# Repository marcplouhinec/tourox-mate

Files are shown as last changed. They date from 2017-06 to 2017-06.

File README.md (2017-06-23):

# Tourox Mate

## Introduction
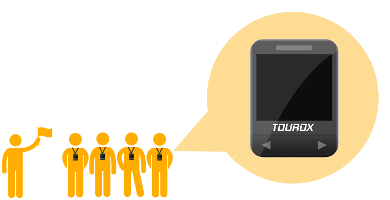
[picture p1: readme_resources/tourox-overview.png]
Product overview


Tourox Mate is a device that helps tour guides during group travels. It is worn by each participant with a lanyard.
Each device contains a chip that connects it to internet via the cellular network. The tour guide is thus in permanent
contact with each member of his group via his smartphone.

Tourox Mate provides the following features:
* During travels with a great number of people, the tour guide is immediately warned if a member of the group doesn't
  follow anymore or leave unexpectedly.
  
  Use case: person not following
* During outdoor visits, it happens that the tour guide allows his group members to explore a place by themselves
  (market, city-center, ...) during a given period of time before gathering again in order to resume the visit.
  Thanks to its internet connection, Tourox Mate can:
  * Allow the tour guide to visualize in real-time the geographical position of each group member on a map.
  
    Use case: get tourist location
  * Let a group member to call the guide in case of a problem.
  
    Use case: tourist calls guide
  * Let the guide to call his group members in case they are late or too far.
  
    Use case: guide calls tourist
* Finally, Tourox Mate can also replace voice transmission devices.

  Use case: voice transmitter

Technically, Tourox Mate is made of the following parts:
 * A physical device, made with electronics, a 3D printed case and a firmware.
 * A web-server collecting information from devices over internet.
 * An Android application for the Tour Guide that allows him to configure and interact with the physical devices.
 
## Build
Please follow the following instructions if you want to build Tourox Mate yourself:
1. [Build the physical device.](device/README.md)
2. [Build and setup the web-server](webserver/README.md)
2. [Build and setup the tour guide Android application](android/README.md)

## Usage
The current version is a prototype so only the basic features are available.

To start using Tourox Mate, turn on the device with the slide switch and open the "Tourox Device Tester" app on the
Android device. The Android application scans for bluetooth devices and quickly find the Tourox Mate:

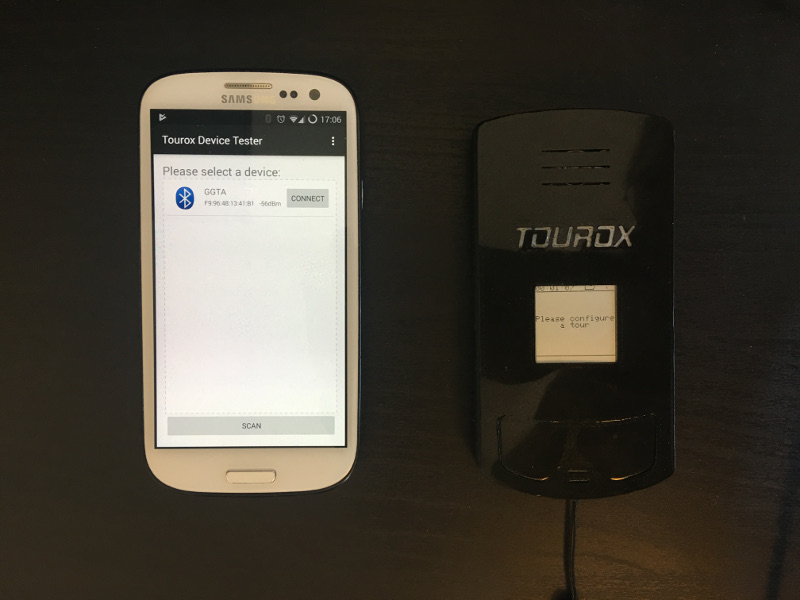
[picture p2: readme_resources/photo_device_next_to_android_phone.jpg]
Device next to Android phone


When you select this device, the following screen opens:

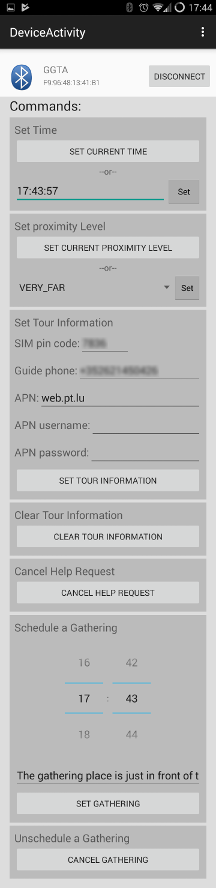
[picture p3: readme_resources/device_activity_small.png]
Device activity


It allows you to execute the following actions:
* Set the device time.
* Set the proximity level that reflects the distance between the tour guide and a tourist wearing the device.
* Configure a tour with the following properties:
  * The SIM card PIN number.
  * The [APN](https://en.wikipedia.org/wiki/Access_Point_Name) with the corresponding username and password.
    These values can be found on the telecom provider contract or support website.
  * The tour guide phone number. It is the number the device will call when the tourist presses the "HELP" button.
* Clear the tour configuration.
* Cancel a help request on the device.
* Schedule a gathering with the following properties:
  * The gathering time.
  * A gathering text description.
* Un-schedule a gathering.

To start using the device, set the time and proximity level, and configure a tour:

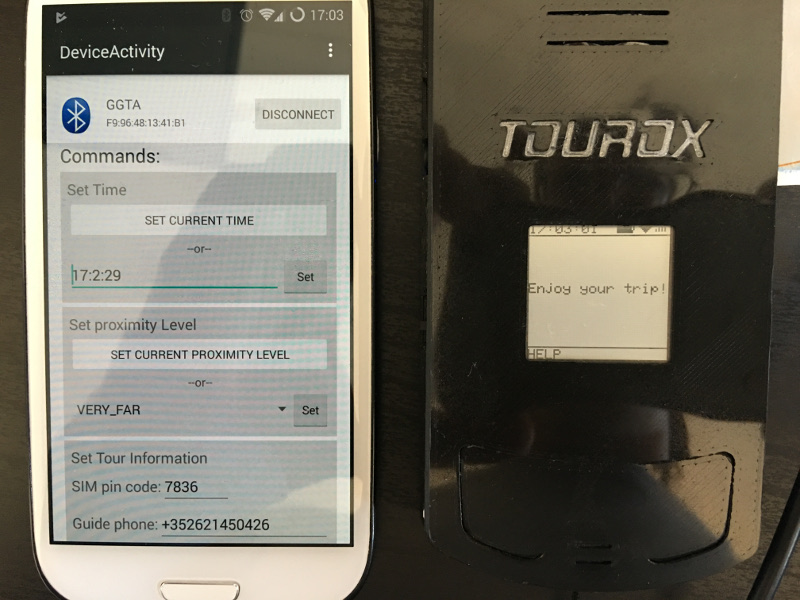
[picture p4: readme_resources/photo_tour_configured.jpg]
Tour configured


From the device, a tourist can call the tour guide by pressing on the help button:

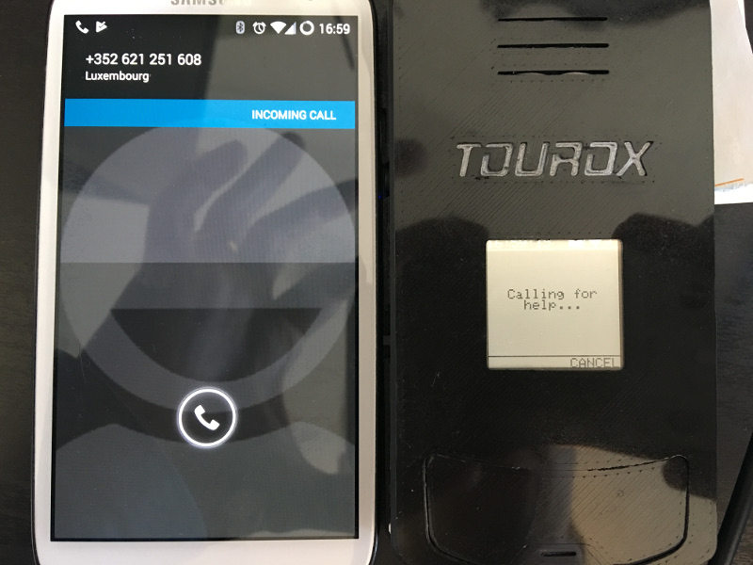
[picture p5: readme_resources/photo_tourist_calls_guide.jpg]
Tourist calls guide


In a similar way, the tour guide can also call the device by dialing its number:

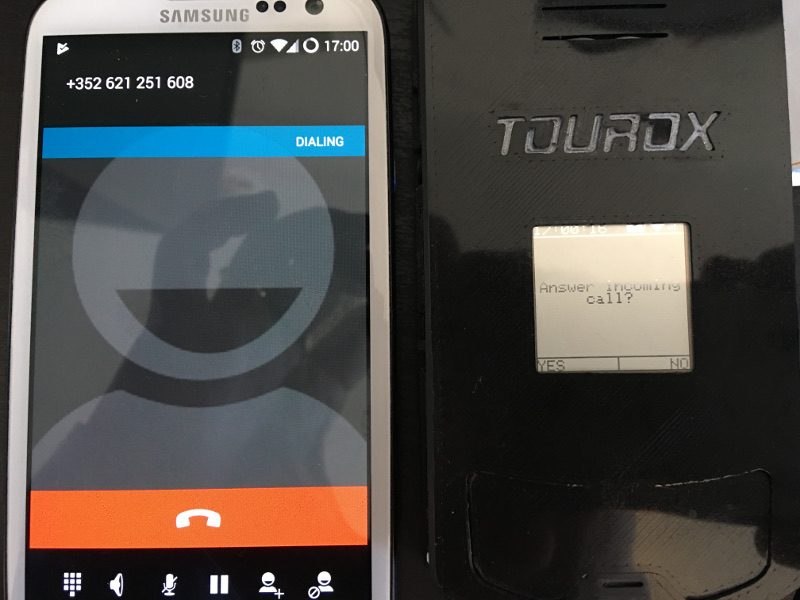
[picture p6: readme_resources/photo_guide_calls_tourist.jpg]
Guide calls tourist


The tour guide can see the device location by browsing to the webserver URL:

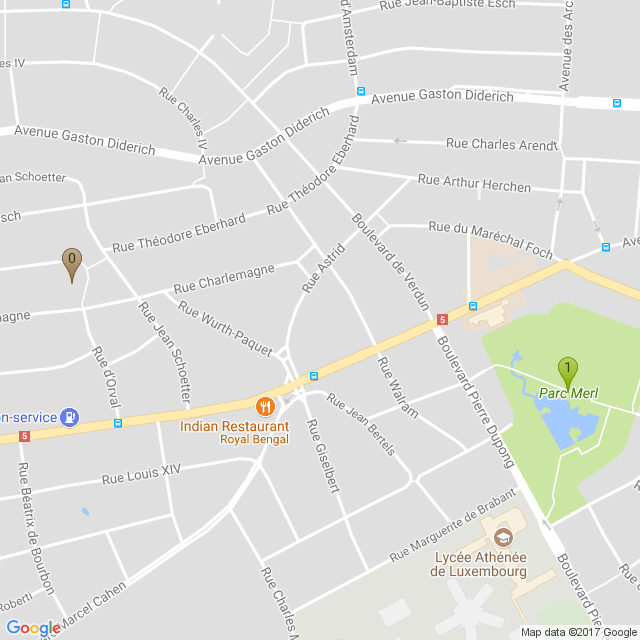
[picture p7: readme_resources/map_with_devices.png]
Map with devices


When the tour guide schedules a gathering, the device shows the gathering description:

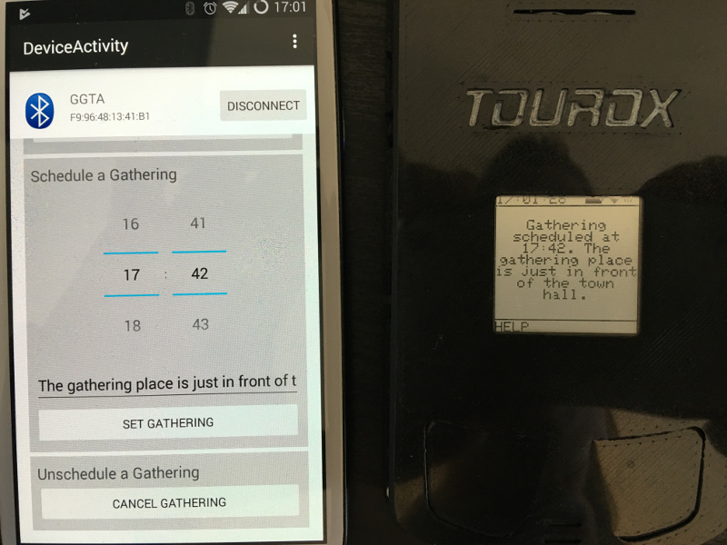
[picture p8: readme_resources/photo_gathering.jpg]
Gathering


Canceling a gathering reverts the device to its normal state.

Finally, to disconnect the device from internet, the tour guide can clear the tour configuration.

___

Thank you for reading! don't hesitate to contact me if you have any remark or question!

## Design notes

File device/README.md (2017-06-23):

# Tourox Mate - Device

## Introduction
As explained in the [parent document](../README.md), the goal of this device is to allow a tour guide to stay
in permanent contact with his group members during a trip. Each tourist wears a device with a lanyard.

The current version has the following communication capabilities:
* It can connect directly to the tour guide's smartphone via [BLE](https://en.wikipedia.org/wiki/Bluetooth_Low_Energy).
  This protocol allows the guide to configure a device, send text messages and measure the distance.
* It can use the standard GSM network to give phone calls (tour guide to tourist and vice versa).
* It can get its geographical position (latitude and longitude) thanks to the cellular network.
* It can connect to a server over internet via [GPRS](https://en.wikipedia.org/wiki/General_Packet_Radio_Service) in
  order to regularly send its location.

## Components
The following diagram shows the components and how they are connected:

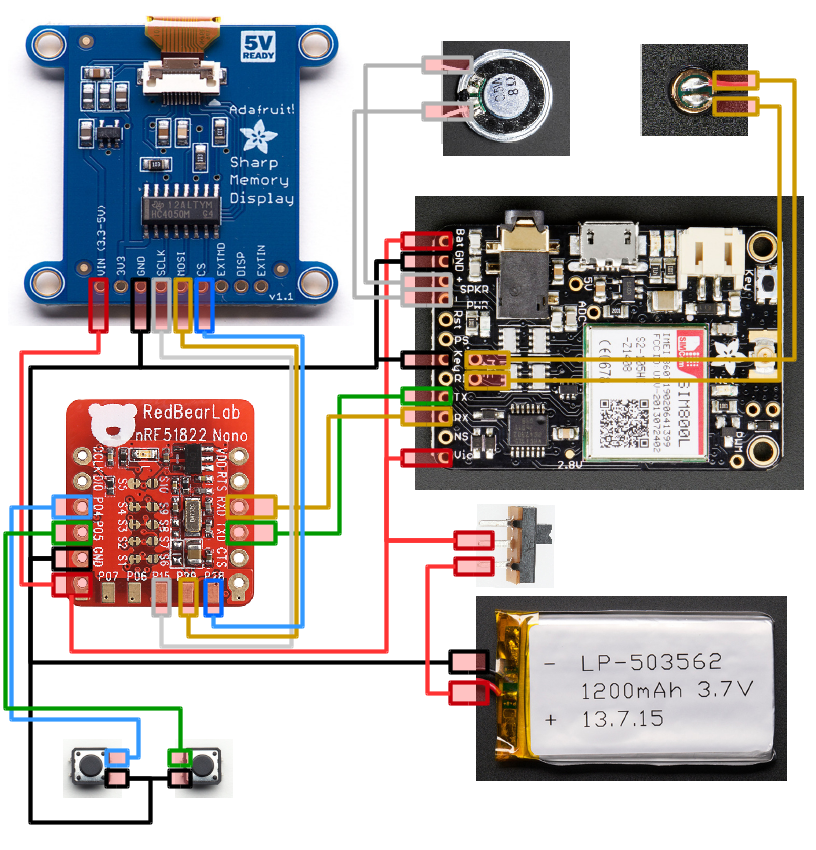
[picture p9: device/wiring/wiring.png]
Components and wires


The brain of the system is a [nRF51822](https://www.nordicsemi.com/eng/Products/Bluetooth-low-energy/nRF51822), a
low-power SoC containing an ARM Cortex M0 CPU and a BLE module. It is located on the 
[RedBearLab BLE Nano](http://redbearlab.com/blenano/) board. For development I also used a
[nRF51 DK](https://www.nordicsemi.com/eng/Products/nRF51-DK) board, which is optional but more convenient at this stage.

The screen is a low-power [SHARP LCD display](https://www.adafruit.com/product/1393) packaged on a board produced
by AdaFruit.

The GSM module is an [AdaFruit FONA](https://www.adafruit.com/product/1946) powered with a
[SIM800](http://simcomm2m.com/En/module/detail.aspx?id=138) chip. It handles voice calls and provides an
internet connection. A typical [SIM card](https://en.wikipedia.org/wiki/Subscriber_identity_module)
(there is a socket under the board) and a [uFL GSM Antenna](https://www.adafruit.com/product/1991) are necessary.
In addition, this module can even recharge a LiPo battery.

Finally, the device also contains a [1200mAh LiPo battery](https://www.adafruit.com/product/258),
a [8 ohm 0.5W speaker](https://www.adafruit.com/product/1890),
an [electret microphone](https://www.adafruit.com/product/1064),
two [tactile buttons](https://www.adafruit.com/product/367),
a [SPDT Slide Switch](https://www.adafruit.com/product/805),
[stranded-core 22AWG wires](https://www.adafruit.com/product/3111),
[0.1" male](https://www.adafruit.com/product/392) and [female headers](https://www.adafruit.com/product/598).

## Building steps

### Case 3D printing
The case as been designed with [OpenSCAD](http://www.openscad.org/), a tool that allows developers to create
3D models with a scripting language. It is free and available on most operating systems. The advantages of using a
scripting language instead of a graphical mouse-controlled CAD software like [Thingiverse](https://www.thingiverse.com/)
is that it is very easy to parametrize (for example sizes and positions can be saved in variables and used by
several parts of the code, which is useful for connectors or components that need to fit together),
it is [VCS-friendly](https://en.wikipedia.org/wiki/Version_control) (for example
difference between several versions of a script can be easily visualized on GitHub) and reusable
[part libraries](https://github.com/openscad/openscad/wiki/Libraries) can be shared on internet. The main disadvantage
is that is it harder to use, especially for beginners.

In order to visualize the 3D model, setup OpenSCAD on your computer and open the `3dmodel/Box.scad` file. You should
then see something like this:

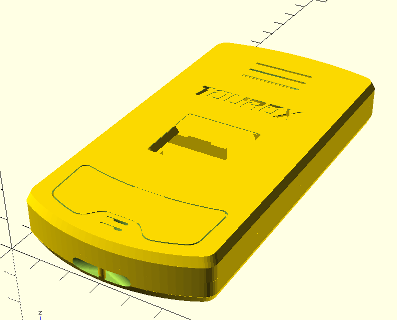
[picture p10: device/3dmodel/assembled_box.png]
3D model - assembled box


Before printing the case, you need to generate [STL files](https://en.wikipedia.org/wiki/STL_(file_format)). To do that,
scroll the text editor to the bottom of the file `3dmodel/Box.scad`:

    //rotate([0, 180, 0])
    Box_assembled(includeBackCover = true, includeFrontCover = true, includeComponents = false);

These two lines generate the assembled box, which cannot be used directly. Modify these two lines like this:

    //rotate([0, 180, 0])
    Box_assembled(includeBackCover = true, includeFrontCover = false, includeComponents = false);

You should then see the following 3D model, which is the back cover:

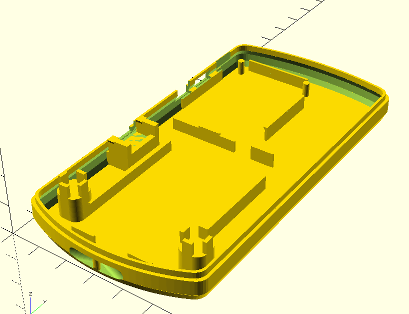
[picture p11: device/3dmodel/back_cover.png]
3D model - back cover


Then render it and export it as `back_cover.stl`.

In order to generate the front cover, modify the last two lines like this:

    rotate([0, 180, 0])
    Box_assembled(includeBackCover = false, includeFrontCover = true, includeComponents = false);

You should then see the following 3D model:

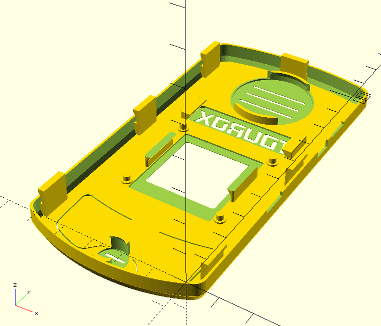
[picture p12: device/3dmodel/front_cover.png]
3D model - front cover


Then render it and export it as `front_cover.stl`.

Finally, if you want, generate the brand label by opening the file `3dmodel/BrandName.scad`, and modify the last
lines like this:

    /*
    difference() {
        BrandName_frame(1, true);
        BrandName_frame(1, false);
    }*/
    
    rotate([0, 180, 0])
        difference() {
            BrandName_coloredBrandName(1, true);
            BrandName_coloredBrandName(1, false);
        }

You should then see something like this:

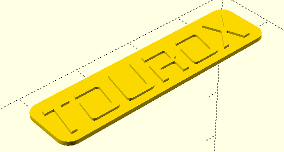
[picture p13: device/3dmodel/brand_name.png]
3D model - brand name


Then render it and export it as `brand_name.stl`.

You can then use your favorite tools to generate [G-code](https://en.wikipedia.org/wiki/G-code) for each STL file and
send them to your 3D printer, with tools like [Slic3r](http://slic3r.org/) +
[Printrun](http://www.pronterface.com/) or [Cura](https://ultimaker.com/en/products/cura-software).

If you are lucky, the result should look like this:

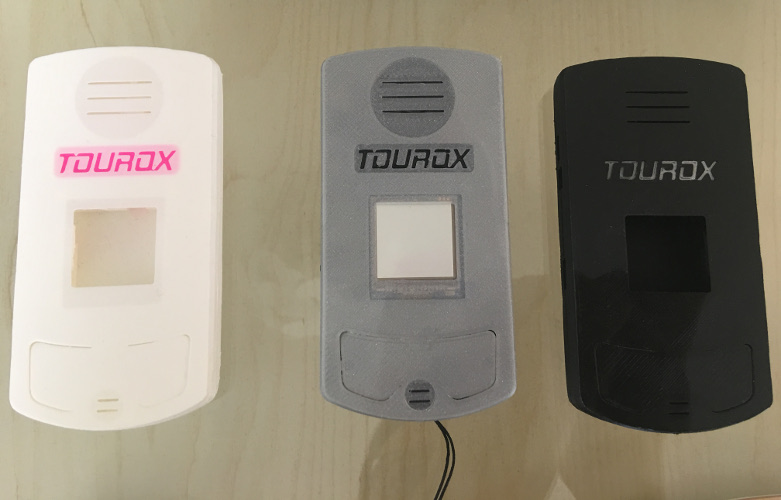
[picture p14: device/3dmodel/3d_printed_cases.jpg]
3D printed cases


### Wiring
Now that the case is ready, it is time to add electronic components in it!

Because 22AWG wire are quite thick, it is important to place components in order to avoid too many wire crossings.
The following schema is useful for preparing wires before soldering them on the back cover:

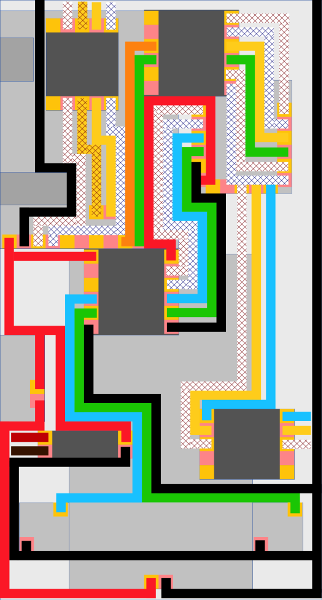
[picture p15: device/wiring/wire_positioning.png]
Wire positioning


To print this schema with the right size, install [LibreOffice](https://www.libreoffice.org/), open and print the file
`wiring/wire_positioning.odg`.
The following photo shows how to prepare the wires according to this schema (the same photo at bigger resolution
is [available here](wiring/photo_wire_positioning.jpg)):

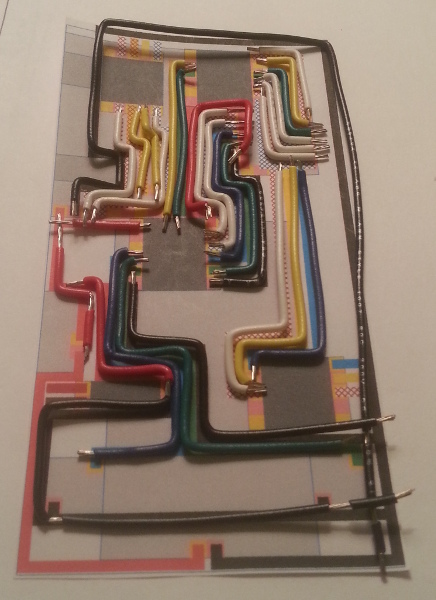
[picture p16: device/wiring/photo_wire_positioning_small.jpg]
Wire positioning photo


As you can see on the schema, 0.1" headers must be prepared at the following size:
* 6 pins for connecting the RedBearLab Nano with the Adafruit FONA.
* 4 pins for connecting the Adafruit FONA with the speaker and microphone (the schema shows 5 pins but you can put less).
* 6 pins for connecting the RedBearLab Nano with the tactile buttons and battery.
* 3 pins for connecting the RedBearLab Nano with the screen (the schema shows 5 pins but you can put less).
* 2 pins for connecting the screen with the battery.

As you can see, the RedBearLab Nano have more soldered wires connected to headers than necessary, but it is useful
for flashing the microcontroller by connecting it to the [MK20 USB Board](http://redbearlab.com/blenano/#mk20usbboard).

The following photo shows the wires soldered and connected to each others (a bigger resolution is
[available here](wiring/photo_wired_components.jpg)):

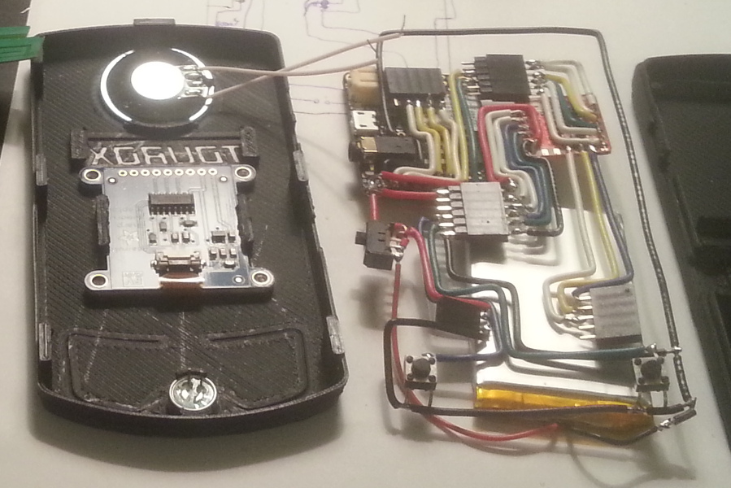
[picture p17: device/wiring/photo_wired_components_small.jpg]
Connected wires photo


Positioning wires on the front cover is much simpler, no need to prepare a shema for that, the following photo
is clear enough:

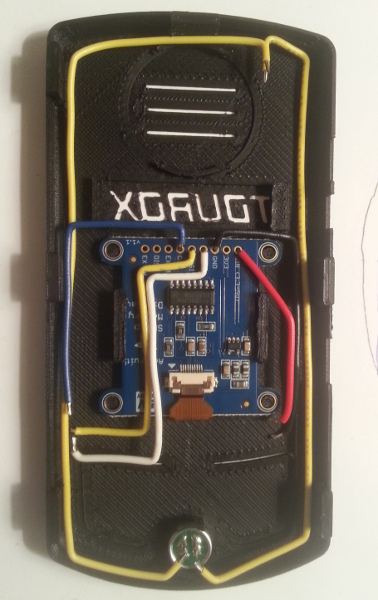
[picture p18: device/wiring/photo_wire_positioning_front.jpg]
Front wires photo


The following photos shows both covers with connected components (a bigger resolution is
[available here](wiring/photo_components_placed_and_connected.jpg)):

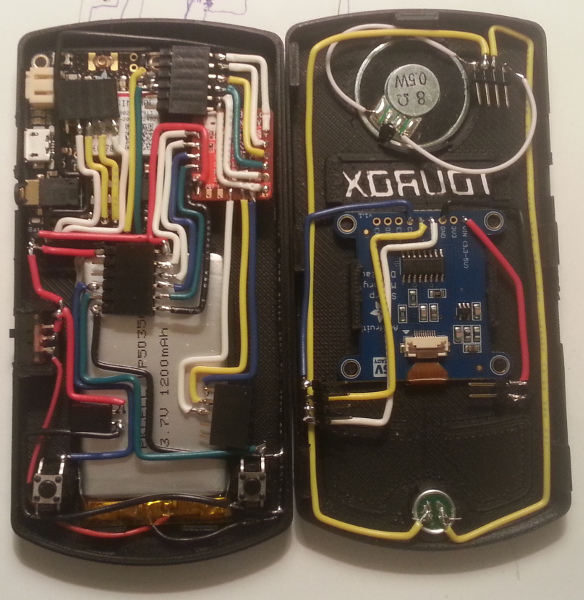
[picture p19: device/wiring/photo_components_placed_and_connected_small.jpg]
Connected components photo


### Electromagnetic shielding
There is a missing but important component is the previous photo: the GSM antenna. If you "naively" put it inside the
case you will experience unexpected resets because the GSM signal interferes with the microcontroller.

To solve this problem, you can create a layer of [aluminium foil](https://en.wikipedia.org/wiki/Aluminium_foil)
in sandwich between two layers of paper. And then put this in the middle of the case with the RedBearLab Nano on one
side (back cover side) and the GSM antenna on the other side (front cover side).

The following photos show how you can reproduce this protection:

* Electromagnetic shield width ([bigger resolution](electromagnetic_shield/photo_shield_width.jpg)):

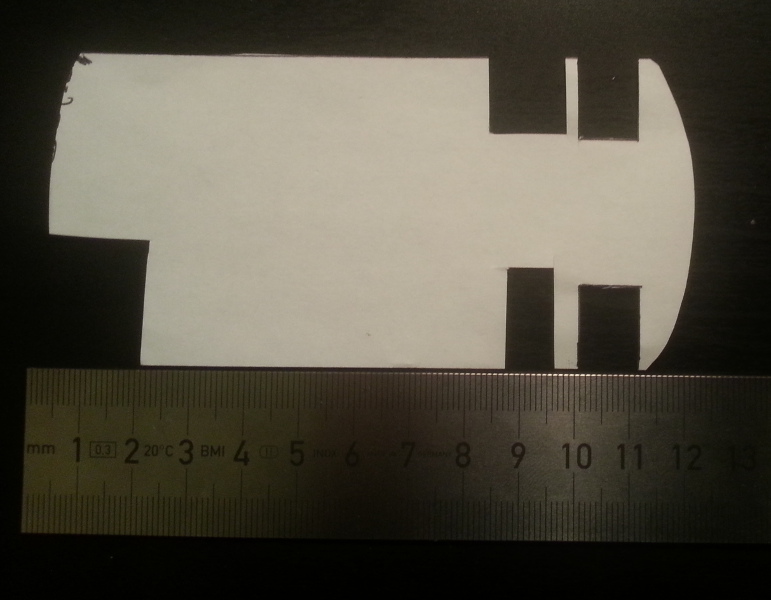
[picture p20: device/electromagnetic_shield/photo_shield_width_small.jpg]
Shield width


* Electromagnetic shield height ([bigger resolution](electromagnetic_shield/photo_shield_height.jpg)):

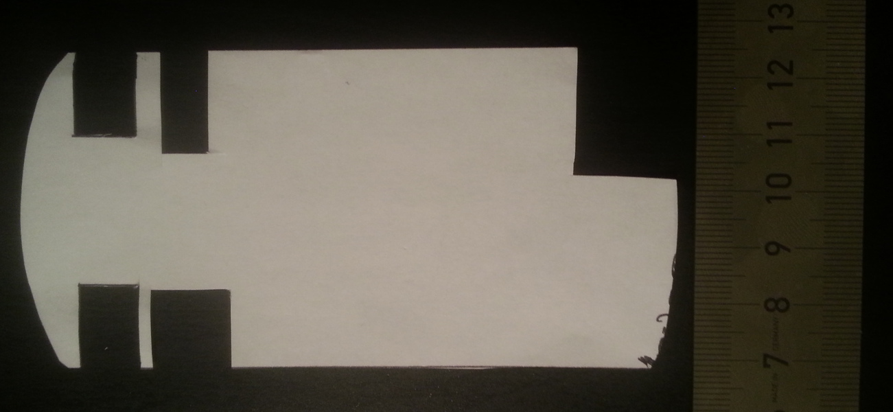
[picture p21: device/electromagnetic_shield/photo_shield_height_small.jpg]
Shield height


* Electromagnetic shield in place ([bigger resolution](electromagnetic_shield/photo_shield_in_place.jpg)):

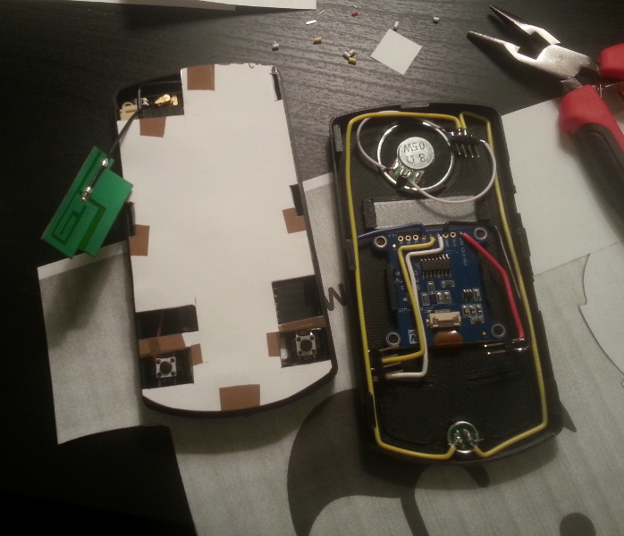
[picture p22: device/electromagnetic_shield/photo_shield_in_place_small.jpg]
in place Shield in place


### Compile and flash the firmware
This is the step where you will discover all your wiring or soldering mistakes! :-)

#### Setup development environment
The following section describes briefly how to setup your environment in order to compile the firmware with
[GCC](https://gcc.gnu.org/).

Detailed information about how to setup [Eclipse IDE](https://www.eclipse.org) can be found in
[this tutorial](https://devzone.nordicsemi.com/tutorials/7/development-with-gcc-and-eclipse/) from Nordic Semiconductor.

1. Setup the [GNU toolchain for ARM Cortex-M](https://developer.arm.com/open-source/gnu-toolchain/gnu-rm/downloads).
2. Add the toolchain into the PATH environment variable. To check if it is correctly set, open a new terminal
   and type the following command:
   ```bash
   arm-none-eabi-gcc --version
   ```
   The result should be something like this:
   ```text
   arm-none-eabi-gcc (GNU Tools for ARM Embedded Processors 6-2017-q1-update) 6.3.1 20170215 (release) [ARM/embedded-6-branch revision 245512]
   Copyright (C) 2016 Free Software Foundation, Inc.
   This is free software; see the source for copying conditions.  There is NO
   warranty; not even for MERCHANTABILITY or FITNESS FOR A PARTICULAR PURPOSE.
   ```
3. Setup GNU Make:
  * On Linux, setup the package provided by your distribution, like `build-essential` on Debian.
  * On Windows, setup the GNU ARM Eclipse Windows Build Tools package from the
    [GNU ARM Eclipse plug-in project](http://gnuarmeclipse.github.io/windows-build-tools/).
  * On MAC OSX, setup the 
    [Xcode tools](https://developer.apple.com/library/mac/documentation/Darwin/Reference/ManPages/man1/gnumake.1.html).
  * Check the result by opening a new terminal and by typing the following command:
     ```bash
     make -v
     ```
     The result should be something like this:
     ```text
     GNU Make 3.81
     Copyright (C) 2006  Free Software Foundation, Inc.
     This is free software; see the source for copying conditions.
     There is NO warranty; not even for MERCHANTABILITY or FITNESS FOR A
     PARTICULAR PURPOSE.
     
     This program built for i386-apple-darwin11.3.0
     ```
4. Setup the nRF5x-Command-Line-Tools
  * Download the nRF5x-Command-Line-Tools from the 
    [Nordic Semiconductor download page](https://www.nordicsemi.com/eng/Products/Bluetooth-low-energy/nRF51822).
  * On Linux and MAC OSX, unzip the tools archive and add `<nRF5x-Command-Line-Tools>/mergehex` into the PATH
    environment variable.
  * Check the result by opening a new terminal and by typing the following command:
     ```bash
     mergehex --version
     ```
     The result should be something like this:
     ```text
     mergehex version: 9.5.0
     ```
5. Download and unzip the [Nordic nRF5x SDK 8.1.0](http://developer.nordicsemi.com/) (a greater version may not be
   compatible).
6. Edit the SDK Makefile with a text editor:
  * On Linux and MAC OSX, open `<SDK>/components/toolchain/gcc/Makefile.posix`.
  * On Windows, open `<SDK>/components/toolchain/gcc/Makefile.posix`.
  * Replace the `GNU_INSTALL_ROOT` property value by the path where you setup the GNU toolchain and `GNU_VERSION`
    by the toolchain version:
    ```text
    GNU_INSTALL_ROOT := /opt/gcc-arm-none-eabi-6-2017-q1-update
    GNU_VERSION := 6.3.1
    GNU_PREFIX := arm-none-eabi
    ```
7. With a text editor open the project file `device/firmware/Makefile` and replace the following property values:
  * `TARGET_BOARD` with `TARGET_BOARD_IS_BLE_NANO`
  * `SDK_PATH` with the path where you unzipped the Nordic nRF5x SDK (e.g. `/opt/nRF51_SDK_8.1.0_b6ed55f`).

#### Configure the firmware
The firmware needs the URL of the [webserver](../webserver) where it will send the device location. It means that
you need to have a server with a public IP address that the device can reach from the GPRS connection.

If you want you can pause here and start installing the [webserver](../webserver). Once you have the URL of your
server, you can resume this firmware configuration. A typical URL would be "http://myhostname.com/tourox/".

To configure the firmware, open the file `service/service_geolocation.c` and find the following constants:
```c
#define SEND_GEOLOCATION_URL               "http://www.tourox.io/sl/imeiimeiimeiime/-xx.dddddd/-xx.dddddd"
#define SEND_GEOLOCATION_URL_LENGTH        (sizeof(SEND_GEOLOCATION_URL))
#define SEND_GEOLOCATION_URL_IMEI_POS      (sizeof("http://nwww.tourox.io/sl"))
#define SEND_GEOLOCATION_URL_LNGLAT_POS    (sizeof("http://www.tourox.io/sl/imeiimeiimeiime"))
```
replace them by
```c
#define SEND_GEOLOCATION_URL               "http://myhostname.com/tourox/sl/imeiimeiimeiime/-xx.dddddd/-xx.dddddd"
#define SEND_GEOLOCATION_URL_LENGTH        (sizeof(SEND_GEOLOCATION_URL))
#define SEND_GEOLOCATION_URL_IMEI_POS      (sizeof("http://myhostname.com/tourox/sl"))
#define SEND_GEOLOCATION_URL_LNGLAT_POS    (sizeof("http://myhostname.com/tourox/sl/imeiimeiimeiime"))
```

> Note the pattern: replace "http://www.tourox.io/" with your URL "http://myhostname.com/tourox/".

In fact it is a bad practice to hardcode an URL inside a firmware. Instead, a better solution would be to set
it each time the Android application configures the device. But it is good enough for a prototype. :-)

#### Compile the firmware
To compile with a command line, type the following commands:
```bash
make
make nrf51422_xxac_s110 package
```

#### Prepare the MK20 USB board
The [MK20 USB board](http://redbearlab.com/blenano/#mk20usbboard) is necessary for flashing the Nano board:

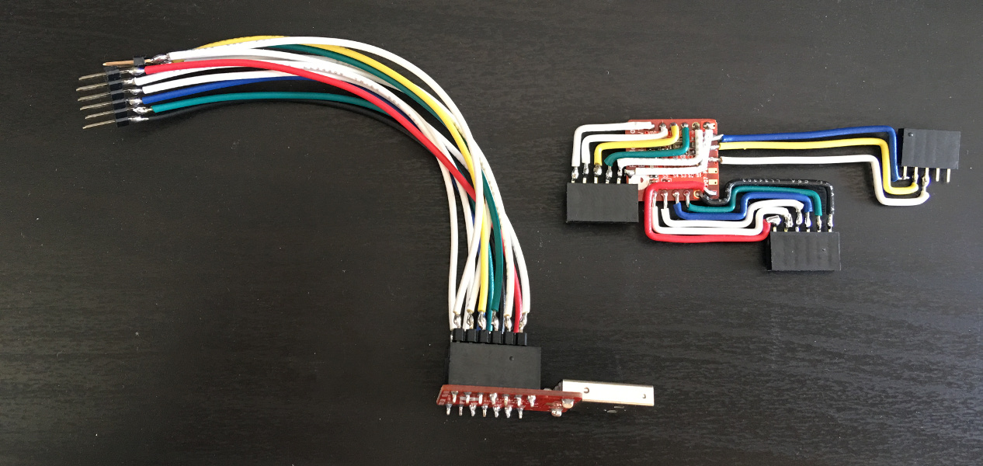
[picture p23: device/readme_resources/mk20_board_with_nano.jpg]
MK20 board with Nano


Solder wires and headers on the MK20 USB board. The wire color code must be the same as the Nano board:

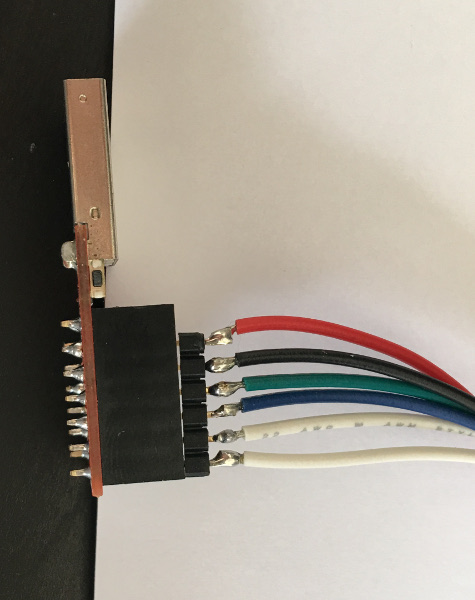
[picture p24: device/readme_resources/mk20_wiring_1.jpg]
MK20 wiring 1

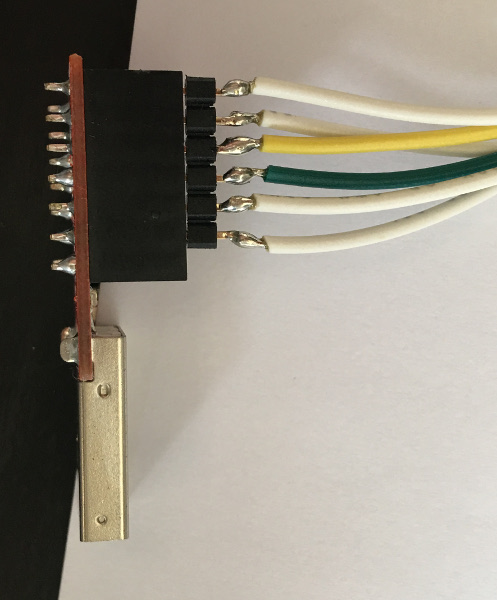
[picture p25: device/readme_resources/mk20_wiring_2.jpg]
MK20 wiring 2


A detailed tutorial about how to compile and flash the board is [available here](http://redbearlab.com/nrf51822-sdk).

#### Flash the RedBearLab Nano board
Plug the RedBearLab Nano board to the MK20 USB board and the later to the computer:

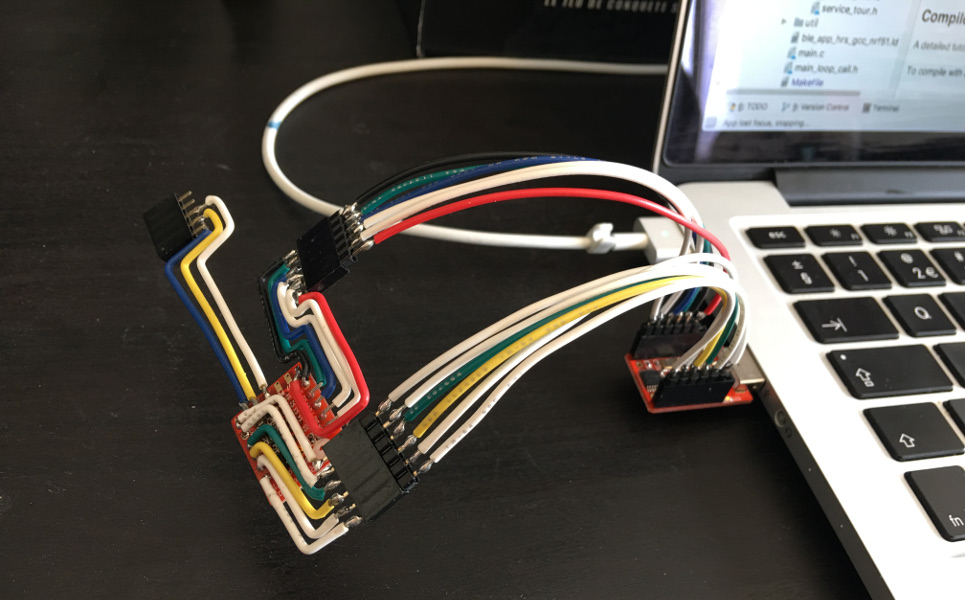
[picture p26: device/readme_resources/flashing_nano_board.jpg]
Flash Nano board


A new USB drive will appear with the "MBED" name.
Copy the file `_build/nrf51422_xxac_s110_packed.hex` into this drive.

After few seconds the MBED drive will refresh itself without the .hex file you just copied. At this stage, unplug the
board and put back the Nano into the Tourox case and close it.

If everything works as expected, you should see it working!

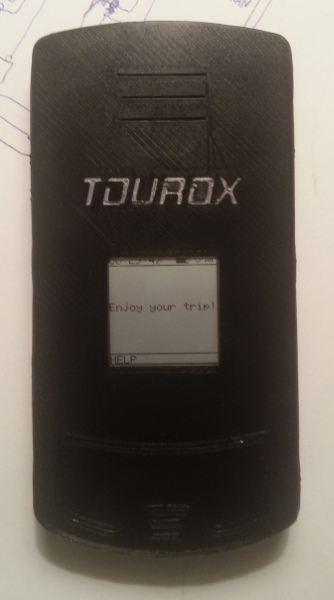
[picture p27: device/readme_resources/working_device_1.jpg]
Working device 1

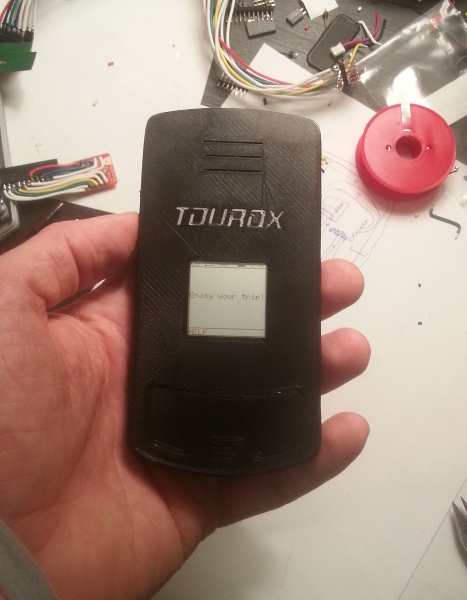
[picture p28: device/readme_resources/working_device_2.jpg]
Working device 2


To actually use your device, you also need to build the Android and server applications. Please follow the
next instructions in the [parent document](../README.md).

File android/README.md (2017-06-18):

# Tourox Mate - Android application

## Introduction
The goal of this Android application is to configure and control the physical device. It is more a "device tester" than
a real application for tour guides.

The Android device must have an OS version equal or greater than Android 4.3 (Jelly Bean), and must support
[BLE](https://en.wikipedia.org/wiki/Bluetooth_Low_Energy).

## Build and installation
In order to build the Android application, please execute the following instructions:
* Download and setup [Android Studio](https://developer.android.com/studio/index.html).
* Checkout this project on your computer, and open the `android` folder with Android Studio.
* Follow the Android Studio instructions to install the required SDKs and tools.
* Plug your Android device to the computer with USB debugging enabled.
* Run the application by clicking on the *Run* toolbar button.

Please read the "usage" section of the [parent document](../README.md) for more information about how to use Tourox Mate.

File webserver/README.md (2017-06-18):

# Tourox Webserver

## Introduction
The goal of the Tourox webserver is to collect tourist device geolocations, and allow the tour guide to view
them on a map.

Warning: the current version of this server is a prototype so all information is public (no access enforcement).

## Technologies
* [Java 8](http://www.oracle.com/technetwork/java/javase/overview/java8-2100321.html)
* [Spring Boot](https://projects.spring.io/spring-boot/)
* [Spring Data JPA](http://projects.spring.io/spring-data-jpa/)
* [HSQLDB](http://hsqldb.org/)
* [Apache HTTP Server](https://httpd.apache.org/) as a reverse proxy

## Build
The scripts in this section target the [Debian](https://www.debian.org/) operating system.

After cloning the repository from GitHub, type the following commands:

    cd webserver
    mvn clean install
    chmod +x build-deb-package.sh
    ./build-deb-package.sh $(git rev-parse --short HEAD)

The package is named: "./target/touroxwebserver_1.0.0.GIT_HASH_all.deb"

## Installation
Copy the .deb package on your server and stop the existing version if applicable:

    sudo service touroxwebserver stop
    
Install the package:

    sudo dpkg -i ./touroxwebserver_1.0.0.GIT_HASH_all.deb
    sudo apt-get -f install

Adapt the Apache configuration file:

    cd /etc/touroxwebserver
    vi logback.xml
    cd /etc/apache2/conf.d
    vi touroxwebserver

> Warning: the server IP must be accessible from internet, if not the device will not be able to connect to the server
> via its GPRS connection.

Start the service:

    sudo service touroxwebserver start
    sudo service apache2 restart

The logs are located in the folder /var/log/touroxwebserver.

## Usage
The webserver is not meant to be directly used by a human, but testing can be done with [curl](https://curl.haxx.se/).

To add some device location into the database, type the following command in a terminal:

    curl http://<hostname>:<port>/sl/<device IMEI>/<longitude>/<latitude>
    
Example:

    curl http://localhost:8080/sl/012345678901234/6.101516/49.607767
    curl http://localhost:8080/sl/012345678955555/6.112162/49.606249
    
To read the location of all devices, type the following command:

    curl http://<hostname>:<port>/device/locations
    
Example:

    curl http://localhost:8080/device/locations

Example result:
```json
[
  {
    "id": 1,
    "imei": "012345678901234",
    "latitude": 49.607767,
    "longitude": 6.101516,
    "lastUpdateDate": 1497810099518
  },
  {
    "id": 2,
    "imei": "012345678955555",
    "latitude": 49.606249,
    "longitude": 6.112162,
    "lastUpdateDate": 1497810141561
  }
]
```

You can also browse the URL `http://<hostname>:<port>` with a web browser like [Mozilla Firefox](https://www.mozilla.org/)
to see a map with device locations.

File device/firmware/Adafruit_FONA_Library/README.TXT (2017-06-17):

Port of an Arduino library for Mbed by Marc PLOUHINEC (m_plouhinec@yahoo.fr).
Last update: 07/10/2015

The original code is available here: https://github.com/adafruit/Adafruit_FONA_Library

Original README.TXT file content:
=================================

Adafruit_FONA_Library
=====================

**This library requires Arduino v1.0.6 or higher**

This is a library for the Adafruit FONA Cellular GSM Breakouts etc

Designed specifically to work with the Adafruit FONA Breakout
  * https://www.adafruit.com/products/1946
  * https://www.adafruit.com/products/1963
  * http://www.adafruit.com/products/2468
  * http://www.adafruit.com/products/2542

These modules use TTL Serial to communicate, 2 pins are required to interface

Adafruit invests time and resources providing this open source code, 
please support Adafruit and open-source hardware by purchasing 
products from Adafruit!

Check out the links above for our tutorials and wiring diagrams 

Written by Limor Fried/Ladyada for Adafruit Industries.  
BSD license, all text above must be included in any redistribution
With updates from Samy Kamkar

To download. click the DOWNLOADS button in the top right corner, rename the uncompressed folder Adafruit_FONA 
Check that the Adafruit_FONA folder contains Adafruit_FONA.cpp and Adafruit_FONA.h

Place the Adafruit_FONA library folder your *arduinosketchfolder*/libraries/ folder. 
You may need to create the libraries subfolder if its your first library. Restart the IDE.

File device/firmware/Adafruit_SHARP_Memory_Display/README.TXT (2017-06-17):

Port of an Arduino library for nRF51 SDK by Marc PLOUHINEC (m_plouhinec@yahoo.fr).
Last update: 04/10/2015

The original code is available here: https://github.com/adafruit/Adafruit_SHARP_Memory_Display

Original README.TXT file content:
=================================

This is an Arduino library for our Monochrome SHARP Memory Displays

  Pick one up today in the adafruit shop!
  ------> http://www.adafruit.com/products/1393

These displays use SPI to communicate, 3 pins are required to  
interface

To install this library, check out our detailed library install tutorial:
http://learn.adafruit.com/adafruit-all-about-arduino-libraries-install-use

Also requires the Adafruit GFX library, install the same way
https://github.com/adafruit/Adafruit-GFX-Library

Adafruit invests time and resources providing this open source code, 
please support Adafruit and open-source hardware by purchasing 
products from Adafruit!

Written by Limor Fried & Kevin Townsend  for Adafruit Industries.  
BSD license, check license.txt for more information
All text above, and the splash screen must be included in any redistribution

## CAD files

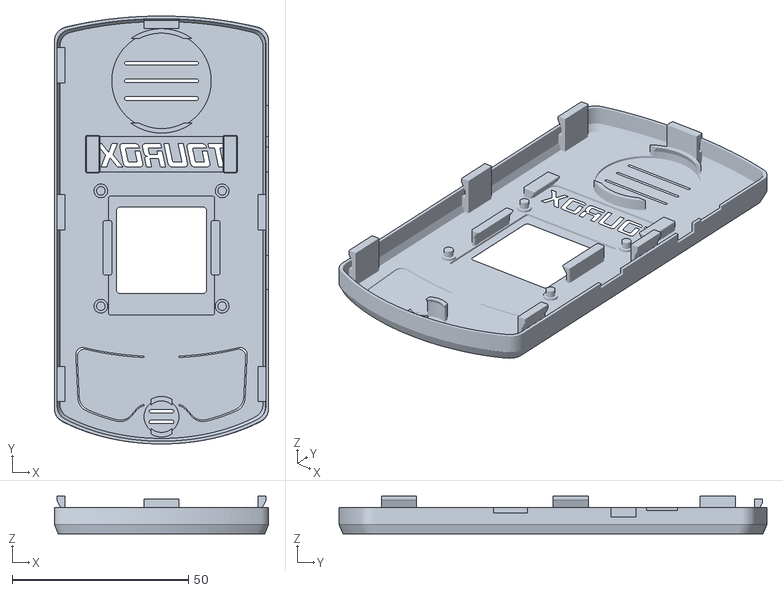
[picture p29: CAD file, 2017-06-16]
device/3dmodel/front_cover.stl
60.8 x 121.4 x 10.8

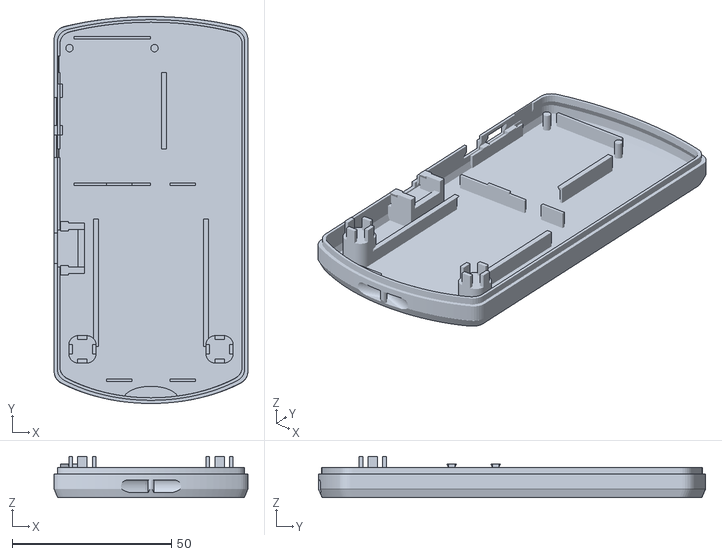
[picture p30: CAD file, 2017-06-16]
device/3dmodel/back_cover.stl
60.8 x 121.4 x 13.0

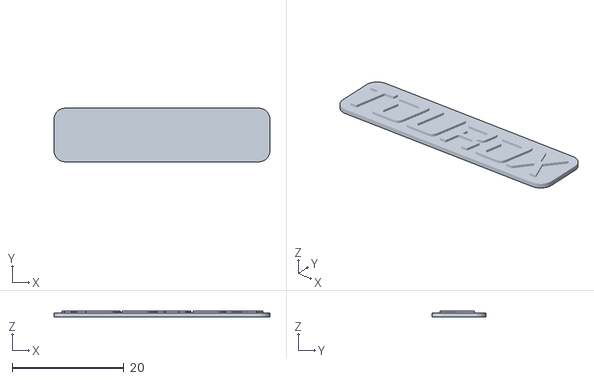
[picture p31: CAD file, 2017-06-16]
device/3dmodel/brand_name.stl
38.6 x 9.60 x 1.10

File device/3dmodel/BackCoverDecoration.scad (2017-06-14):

use <Box.scad>;
use <Fona.scad>;
use <OnOffSwitch.scad>;
use <Battery1200mAh.scad>;
use <BleNano.scad>;
use <PushButtons.scad>;
use <Lanyard.scad>;

EPSILON = 0.001;

/**
 * Supports, holders and clearances for the back cover.
 *
 * @param positiveShape
 *     if true, draw only the positive part.
 *     if false, draw only the negative part.
 * @param includeComponents
 *     if true, include the components like the battery, switch, ...etc.
 */
module BackCoverDecoration(positiveShape = true, includeComponents = true) {
    // FONA
    fonaYPos = Box_outerCoverDepth() - Box_coverThickness() - Fona_holderDepth() - 5.4;
    translate([Box_coverThickness() - EPSILON + 0.3, fonaYPos, 0]) {
        if (includeComponents)
            color("blue")
                Fona(Box_coverThickness(), positiveShape);
        
        Fona_holder(Box_coverThickness(), positiveShape);
    }
    
    // BLE Nano
    translate([Box_outerCoverWidth() - Box_coverThickness() - BleNano_holderWidth() - 0.4,
               Box_outerCoverDepth() - Box_coverThickness() - BleNano_holderDepth() - 18,
               0]) {
        if (includeComponents)
            color("red")
                BleNano(Box_coverThickness(), positiveShape);
        
        // Note: the support is not necessary since the BLE Nano is already
        // constrained by all its connected wires.
        //BleNano_holder(Box_coverThickness(), positiveShape);
    }
    
    // Battery
    translate([(Box_outerCoverWidth() - Battery1200mAh_holderWidth()) / 2, 6.95, 0]) {
        if (includeComponents)
            color("orange")
                Battery1200mAh(Box_coverThickness(), positiveShape);
        
        Battery1200mAh_holder(Box_coverThickness(), positiveShape);
    }
    
    // On-off switch
    translate([Box_coverThickness() + 0.2, fonaYPos - OnOffSwitch_depth() - 16, 0]) {
        baseThickness = Box_coverThickness() + 4.7;
        
        if (includeComponents)
            color("gray")
                OnOffSwitch(baseThickness, positiveShape);
        OnOffSwitch_holder(baseThickness, positiveShape);
    }
    
    // Push buttons
    translate([Box_outerCoverWidth() / 2, 17, 0]) {
        distanceBetweenButtons = 43;
        buttonBase = Box_coverThickness() + 8.2;
        
        if (includeComponents)
            color("brown")
                PushButtons(buttonBase, distanceBetweenButtons, positiveShape);

        PushButtons_holder(buttonBase, distanceBetweenButtons, positiveShape);
    }
    
    // Lanyard holder
    if (positiveShape) {
        intersection() {
            translate([Box_outerCoverWidth() / 2, 1, 0])
                Lanyard_holder(Box_coverThickness() + 0.8, positiveShape);
                
            Box_cover(inner = false, height = Box_backOuterCoverHeight(), fill = true);
        }
    } else {
        translate([Box_outerCoverWidth() / 2, 1, 0])
                Lanyard_holder(Box_coverThickness() + 0.8, positiveShape);
    }
}


includeComponents = true;
difference() {
    union() {
        Box_backCover();
        BackCoverDecoration(positiveShape = true, includeComponents = includeComponents);
    }
    BackCoverDecoration(positiveShape = false, includeComponents = includeComponents);
}

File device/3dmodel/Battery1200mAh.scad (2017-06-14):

EPSILON = 0.001;

BATTERY1200_WIDTH = 34;
BATTERY1200_DEPTH = 60;
BATTERY1200_HEIGHT = 5;

BATTERY1200_HOLDER_WALL_THICKNESS = 0.8;
BATTERY1200_MARGIN = 0.2;

function Battery1200mAh_holderWidth() =
    BATTERY1200_WIDTH + 2 * (BATTERY1200_HOLDER_WALL_THICKNESS + BATTERY1200_MARGIN);
function Battery1200mAh_holderDepth() =
    BATTERY1200_DEPTH + 2 * (BATTERY1200_HOLDER_WALL_THICKNESS + BATTERY1200_MARGIN);

/**
 * 1200 mAh Battery.
 *
 * @param positiveShape
 *     if true, draw only the positive part.
 *     if false, draw only the negative part.
 */
module Battery1200mAh(baseThickness = 0.8, positiveShape = true) {
    if (positiveShape) {
        translate([BATTERY1200_HOLDER_WALL_THICKNESS + BATTERY1200_MARGIN,
                   BATTERY1200_HOLDER_WALL_THICKNESS + BATTERY1200_MARGIN,
                   baseThickness])
            cube([BATTERY1200_WIDTH, BATTERY1200_DEPTH, BATTERY1200_HEIGHT]);
    }
}

/**
 * 1200 mAh Battery holder.
 *
 * @param positiveShape
 *     if true, draw only the positive part.
 *     if false, draw only the negative part.
 */
module Battery1200mAh_holder(baseThickness = 0.8, positiveShape = true) {
    // Base
    baseWidth = Battery1200mAh_holderWidth();
    baseHeight = Battery1200mAh_holderDepth();
    if (positiveShape)
        cube([baseWidth, baseHeight, baseThickness]);
    
    // Top and bottom walls
    if (positiveShape) {
        wallWidth = 8;
        wallSideMargin = 4;
        for (x = [wallSideMargin, baseWidth - wallWidth - wallSideMargin])
            for (y = [0, baseHeight - baseThickness + BATTERY1200_MARGIN])
                translate([x, y, 0])
                    cube([wallWidth,
                          BATTERY1200_HOLDER_WALL_THICKNESS,
                          BATTERY1200_HEIGHT + baseThickness]);
    }
    
    // Left and right walls
    if (positiveShape) {
        wallDepth = 40;
        horizontalHolderWidth = BATTERY1200_HOLDER_WALL_THICKNESS;
        horizontalHolderHeight = BATTERY1200_HOLDER_WALL_THICKNESS + baseThickness + 
                                 BATTERY1200_HEIGHT - 1;
        
        for (x = [0, baseWidth])
            translate([x, (baseHeight - wallDepth) / 2 + (x > 0 ? wallDepth : 0), 0])
                rotate([0, 0, x > 0 ? 180 : 0]) {
                    cube([BATTERY1200_HOLDER_WALL_THICKNESS, wallDepth, horizontalHolderHeight]);
                    
                    translate([horizontalHolderWidth - EPSILON, 0, horizontalHolderHeight])
                        rotate([-90, 0, 0])
                            linear_extrude(height = wallDepth)
                                polygon(points = [[0, 0],
                                                 [horizontalHolderWidth, 0],
                                                 [0, horizontalHolderWidth + 0.2]]);
                }
            
    }
}

color("orange")
    difference() {
        Battery1200mAh(1, true);
        Battery1200mAh(1, false);
    }

difference() {
    Battery1200mAh_holder(1, true);
    Battery1200mAh_holder(1, false);
}

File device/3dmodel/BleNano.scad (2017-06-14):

EPSILON = 0.001;

BLE_NANO_WIDTH = 18.5;
BLE_NANO_DEPTH = 21;
BLE_NANO_PCB_HEIGHT = 1;
PCB_CORNER_RADIUS = 1.5;

FRONT_COMPONENTS_HEIGHT = 1;
BACK_COMPONENTS_HEIGHT = 3;

HOLDER_WALL_THICKNESS = 0.8;
BLE_NANO_MARGIN = 0.1;

function BleNano_width() = BLE_NANO_WIDTH;
function BleNano_depth() = BLE_NANO_DEPTH;
function BleNano_holderWidth() = BLE_NANO_WIDTH + 2 * (HOLDER_WALL_THICKNESS + BLE_NANO_MARGIN);
function BleNano_holderDepth() = BLE_NANO_DEPTH + 2 * (HOLDER_WALL_THICKNESS + BLE_NANO_MARGIN);

/**
 * BLE nano microcontroller.
 *
 * @param positiveShape
 *     if true, draw only the positive part.
 *     if false, draw only the negative part.
 */
module BleNano(baseThickness = 0.8, positiveShape = true) {
    // Base
    baseX = HOLDER_WALL_THICKNESS + BLE_NANO_MARGIN;
    baseY = HOLDER_WALL_THICKNESS + BLE_NANO_MARGIN;
    if (positiveShape) {
        translate([baseX, baseY, BACK_COMPONENTS_HEIGHT + baseThickness])
            linear_extrude(height = BLE_NANO_PCB_HEIGHT)
                offset(r = PCB_CORNER_RADIUS, $fn = 32)
                    offset(r = -PCB_CORNER_RADIUS, $fn = 32)
                        square([BLE_NANO_WIDTH, BLE_NANO_DEPTH]);
    }
    
    // Front components
    if (positiveShape) {
        width = 15;
        depth = 11.5;
        translate([baseX - (width - BLE_NANO_WIDTH) / 2,
                   baseY + 3,
                   BACK_COMPONENTS_HEIGHT + BLE_NANO_PCB_HEIGHT + baseThickness])
            cube([width, depth, FRONT_COMPONENTS_HEIGHT]);
    }
    
    // Back components
    if (positiveShape) {
        width = 15;
        depth = 17.25;
        translate([baseX - (width - BLE_NANO_WIDTH) / 2, baseY + 1, baseThickness])
            cube([width, depth, BACK_COMPONENTS_HEIGHT]);
    }
}

/**
 * BLE nano holder.
 *
 * @param positiveShape
 *     if true, draw only the positive part.
 *     if false, draw only the negative part.
 */
module BleNano_holder(baseThickness = 0.8, positiveShape = true) {
    // Base
    baseWidth = BleNano_holderWidth();
    baseDepth = BleNano_holderDepth();
    if (positiveShape) {
        linear_extrude(height = baseThickness)
            offset(r = PCB_CORNER_RADIUS, $fn = 32)
                offset(r = -PCB_CORNER_RADIUS, $fn = 32)
                    square([baseWidth, baseDepth]);
    }
    
    // Supports
    if (positiveShape) {
        wallHeight = baseThickness + BACK_COMPONENTS_HEIGHT + baseThickness;
        horizontalTopSupportHeight = 1;
        horizontalTopSupportWidth = 0.6;
        innerClearanceWidth = BLE_NANO_WIDTH + 2 * BLE_NANO_MARGIN;
        innerClearanceDepth = BLE_NANO_DEPTH + 2 * BLE_NANO_MARGIN;
        
        difference() {
            union() {
                // Contour around the BLE Nano
                linear_extrude(height = wallHeight)
                    difference() {
                        offset(r = PCB_CORNER_RADIUS, $fn = 32)
                            offset(r = -PCB_CORNER_RADIUS, $fn = 32)
                                square([baseWidth, baseDepth]);
                
                        translate([HOLDER_WALL_THICKNESS, HOLDER_WALL_THICKNESS])
                            offset(r = PCB_CORNER_RADIUS, $fn = 32)
                                offset(r = -PCB_CORNER_RADIUS, $fn = 32)
                                    square([innerClearanceWidth, innerClearanceDepth]);
                    }
                    
                // Horizontal supports on top of the BLE Nano
                translate([0, 0, wallHeight])
                    difference() {
                        linear_extrude(height = horizontalTopSupportHeight)
                            offset(r = PCB_CORNER_RADIUS, $fn = 32)
                                offset(r = -PCB_CORNER_RADIUS, $fn = 32)
                                    square([baseWidth, baseDepth]);
                
                        scale = [(innerClearanceWidth - 2 * horizontalTopSupportWidth) / 
                                 innerClearanceWidth,
                                 (innerClearanceDepth - 2 * horizontalTopSupportWidth) / 
                                 innerClearanceDepth];
                        translate([HOLDER_WALL_THICKNESS, HOLDER_WALL_THICKNESS, -EPSILON])
                            translate([innerClearanceWidth / 2, innerClearanceDepth / 2])
                                linear_extrude(height = horizontalTopSupportHeight + 2 * EPSILON,
                                               scale = scale)
                                    translate([-innerClearanceWidth / 2, -innerClearanceDepth / 2])
                                        offset(r = PCB_CORNER_RADIUS, $fn = 32)
                                            offset(r = -PCB_CORNER_RADIUS, $fn = 32)
                                                square([innerClearanceWidth, innerClearanceDepth]);
                    }
            }
            
            // Remove the support corners
            cornerSize = HOLDER_WALL_THICKNESS + horizontalTopSupportWidth + 2 + 2 * EPSILON;
            cornerheight = wallHeight + horizontalTopSupportHeight + EPSILON;
            for (y = [-EPSILON, baseDepth - cornerSize + EPSILON])
                for (x = [-EPSILON, baseWidth - cornerSize + EPSILON])
                    translate([x, y, 0])
                        cube([cornerSize, cornerSize, cornerheight]);
            
            // Clearance for the surface pins
            translate([-EPSILON, -EPSILON, wallHeight - 0.5])
                cube([baseWidth + 2 * EPSILON,
                      HOLDER_WALL_THICKNESS + horizontalTopSupportWidth + 2 * EPSILON,
                      horizontalTopSupportHeight + 0.5 + EPSILON]);
        }
    }
}
/*
color("red")
    difference() {
        BleNano(0.8, true);
        BleNano(0.8, false);
    }
*/
difference() {
    BleNano_holder(0.8, true);
    BleNano_holder(0.8, false);
}

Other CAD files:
device/3dmodel/Box.scad
device/3dmodel/BrandName.scad
device/3dmodel/Fona.scad
device/3dmodel/FrontCoverDecoration.scad
device/3dmodel/Lanyard.scad
device/3dmodel/Microphone.scad
device/3dmodel/OnOffSwitch.scad
device/3dmodel/PushButtons.scad
device/3dmodel/Screen.scad
device/3dmodel/Speaker.scad

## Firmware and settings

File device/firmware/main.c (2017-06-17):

/**
 * @brief Group Guided Tour Assistant main file.
 *
 * @author Marc Plouhinec
 */

#include <stdbool.h>
#include <stdint.h>
#include "main_loop_call.h"
#include "app_timer.h"
#include "app_button.h"
#include "nrf_gpio.h"
#include "nordic_common.h"
#include "ble_facade/ble_facade.h"
#include "Adafruit_SHARP_Memory_Display/Adafruit_SharpMem.h"
#include "Adafruit_FONA_Library/Adafruit_FONA.h"
#include "display/display_header.h"
#include "display/display_menu.h"
#include "display/display_message_panel.h"
#include "service/service_time.h"
#include "service/service_fona.h"
#include "service/service_geolocation.h"
#include "activity/activity_manager.h"
#include "activity/activity_header.h"
#include "activity/activity_tour_configuration.h"
#include "activity/activity_main.h"
#include "activity/activity_call_for_help.h"
#include "activity/activity_guide_call.h"
#include "util/logging.h"

//
// Hard-coded constants
//

#define APP_TIMER_PRESCALER      0    /**< Value of the RTC1 PRESCALER register. */
#define APP_TIMER_MAX_TIMERS     10   /**< Maximum number of simultaneously created timers. */
#define APP_TIMER_OP_QUEUE_SIZE  8    /**< Size of timer operation queues. */

#define STATUS_LED_INTERVAL                   APP_TIMER_TICKS(1000, APP_TIMER_PRESCALER)  /**< STATUS_LED blinking interval (ticks). */
#define DISPLAY_MESSAGE_PANEL_INTERVAL        APP_TIMER_TICKS(3000, APP_TIMER_PRESCALER)  /**< Display message panel page change interval (ticks). */
#define SERVICE_TIME_UPDATE_INTERVAL          APP_TIMER_TICKS(1000, APP_TIMER_PRESCALER)  /**< Service time update interval (ticks). */
#define ACTIVITY_HEADER_REFRESH_INTERVAL      APP_TIMER_TICKS(1000, APP_TIMER_PRESCALER)  /**< Activity header refresh interval (ticks). */
#define SERVICE_GEOLOCATION_UPLOAD_INTERVAL   APP_TIMER_TICKS(30000, APP_TIMER_PRESCALER) /**< Activity header refresh interval (ticks). */

#define BUTTON_DETECTION_DELAY   APP_TIMER_TICKS(50, APP_TIMER_PRESCALER) /**< Delay from a GPIOTE event until a button is reported as pushed (in number of timer ticks). */

#define MAX_MAIN_LOOP_CALLABLES 20

//
// I/O pins definitions
//

#ifdef TARGET_BOARD_IS_NRF51_DK
	#define STATUS_LED_PIN_NUMBER     21
	#define DISPLAY_ENABLE_PIN_NUMBER 1 // Unused
	#define DISPLAY_CS_PIN_NUMBER     15
	#define DISPLAY_MOSI_PIN_NUMBER   14
	#define DISPLAY_MISO_PIN_NUMBER   2 // Unused
	#define DISPLAY_SCLK_PIN_NUMBER   13
	#define LEFT_BUTTON_PIN_NUMBER    19
	#define RIGHT_BUTTON_PIN_NUMBER   20
	#define FONA_TX_PIN_NUMBER        5
	#define FONA_RX_PIN_NUMBER        6
	#define FONA_RST_PIN_NUMBER       12
#endif

#ifdef TARGET_BOARD_IS_BLE_NANO
	#define STATUS_LED_PIN_NUMBER     19
	#define DISPLAY_ENABLE_PIN_NUMBER 1 // Unused
	#define DISPLAY_CS_PIN_NUMBER     28
	#define DISPLAY_MOSI_PIN_NUMBER   29
	#define DISPLAY_MISO_PIN_NUMBER   2 // Unused
	#define DISPLAY_SCLK_PIN_NUMBER   15
	#define LEFT_BUTTON_PIN_NUMBER    4
	#define RIGHT_BUTTON_PIN_NUMBER   5
	#define FONA_TX_PIN_NUMBER        9
	#define FONA_RX_PIN_NUMBER        11
	#define FONA_RST_PIN_NUMBER       3
#endif


// Global functions declaration
static void status_led_timeout_handler(void* p_context);
static void display_message_panel_timeout_handler(void* p_context);
static void service_time_update_timeout_handler(void* p_context);
static void activity_header_refresh_timeout_handler(void* p_context);
static void service_geolocation_upload_timeout_handler(void* p_context);

static void app_button_handler(uint8_t pin_no, uint8_t button_action);


// Private variables
static app_timer_id_t m_status_led_timer_id;
static app_timer_id_t m_display_message_panel_timer_id;
static app_timer_id_t m_service_time_update_timer_id;
static app_timer_id_t m_activity_header_refresh_timer_id;
static app_timer_id_t m_service_geolocation_upload_timer_id;
static main_loop_callable_t m_main_loop_callables[MAX_MAIN_LOOP_CALLABLES] = {0};
static uint8_t m_nb_main_loop_callables = 0;


/**
 * @brief Application entry point.
 */
int main(void)
{
	LOG("Starting...\r\n");
	uint32_t err_code;

	// Initialize the STATUS_LED pin
	nrf_gpio_cfg_output(STATUS_LED_PIN_NUMBER);

	// Initialize the display
	Adafruit_SharpMem_init(
			DISPLAY_ENABLE_PIN_NUMBER,
			DISPLAY_CS_PIN_NUMBER,
			DISPLAY_MOSI_PIN_NUMBER,
			DISPLAY_MISO_PIN_NUMBER,
			DISPLAY_SCLK_PIN_NUMBER);
	Adafruit_SharpMem_begin();
	Adafruit_GFX_setRotation(0);
	Adafruit_SharpMem_enableDisplay();
	Adafruit_SharpMem_clearDisplay();
	Adafruit_GFX_setTextSize(1);
	Adafruit_GFX_setTextColor(BLACK);

	// Initialize the FONA
	Adafruit_FONA_init(FONA_TX_PIN_NUMBER, FONA_RX_PIN_NUMBER, FONA_RST_PIN_NUMBER);

	// Initialize timers
	APP_TIMER_INIT(APP_TIMER_PRESCALER, APP_TIMER_MAX_TIMERS, APP_TIMER_OP_QUEUE_SIZE, false);
	err_code = app_timer_create(&m_status_led_timer_id, APP_TIMER_MODE_REPEATED, status_led_timeout_handler);
	APP_ERROR_CHECK(err_code);
	err_code = app_timer_create(&m_display_message_panel_timer_id, APP_TIMER_MODE_REPEATED, display_message_panel_timeout_handler);
	APP_ERROR_CHECK(err_code);
	err_code = app_timer_create(&m_service_time_update_timer_id, APP_TIMER_MODE_REPEATED, service_time_update_timeout_handler);
	APP_ERROR_CHECK(err_code);
	err_code = app_timer_create(&m_activity_header_refresh_timer_id, APP_TIMER_MODE_REPEATED, activity_header_refresh_timeout_handler);
	APP_ERROR_CHECK(err_code);
	err_code = app_timer_create(&m_service_geolocation_upload_timer_id, APP_TIMER_MODE_REPEATED, service_geolocation_upload_timeout_handler);
	APP_ERROR_CHECK(err_code);

	// Initialize buttons (note: it MUST be done after initializing the timer!)
	app_button_cfg_t app_button_cfg[] =
	{
			{LEFT_BUTTON_PIN_NUMBER, false, NRF_GPIO_PIN_PULLUP, app_button_handler},
			{RIGHT_BUTTON_PIN_NUMBER, false, NRF_GPIO_PIN_PULLUP, app_button_handler}
	};
	app_button_init(app_button_cfg, sizeof(app_button_cfg) / sizeof(app_button_cfg[0]), BUTTON_DETECTION_DELAY);
	err_code = app_button_enable();
	APP_ERROR_CHECK(err_code);

	// Initialize services
	service_time_init();
	service_fona_init();
	service_geolocation_init();

	// Initialize the BLE facade
	ble_facade_init(service_fona_get_imei());

	// Initialize the activities
	activity_tour_configuration_init();
	activity_main_init();
	activity_call_for_help_init();
	activity_guide_call_init();

	activity_header_start();
	activity_manager_start_activity(activity_tour_configuration_get_context());

	// Start timers
	err_code = app_timer_start(m_status_led_timer_id, STATUS_LED_INTERVAL, NULL);
	APP_ERROR_CHECK(err_code);
	err_code = app_timer_start(m_display_message_panel_timer_id, DISPLAY_MESSAGE_PANEL_INTERVAL, NULL);
	APP_ERROR_CHECK(err_code);
	err_code = app_timer_start(m_service_time_update_timer_id, SERVICE_TIME_UPDATE_INTERVAL, NULL);
	APP_ERROR_CHECK(err_code);
	err_code = app_timer_start(m_activity_header_refresh_timer_id, ACTIVITY_HEADER_REFRESH_INTERVAL, NULL);
	APP_ERROR_CHECK(err_code);
	err_code = app_timer_start(m_service_geolocation_upload_timer_id, SERVICE_GEOLOCATION_UPLOAD_INTERVAL, NULL);
	APP_ERROR_CHECK(err_code);

	LOG("Started\r\n");

	while (true) {
		ble_facade_wait_for_event();

		// Call the main_loop_callables
		for (uint8_t i = 0; i < m_nb_main_loop_callables; i++)
		{
			m_main_loop_callables[i]();
		}
		m_nb_main_loop_callables = 0;
	}
}

bool call_in_main_loop(main_loop_callable_t callable) {
	if (m_nb_main_loop_callables >= MAX_MAIN_LOOP_CALLABLES)
	{
		return false;
	}

	m_main_loop_callables[m_nb_main_loop_callables] = callable;
	m_nb_main_loop_callables++;

	return true;
}

/**
 * Function called when the STATUS_LED timer tick.
 */
static void status_led_timeout_handler(void* p_context) {
	UNUSED_PARAMETER(p_context);
	nrf_gpio_pin_toggle(STATUS_LED_PIN_NUMBER);
}

/**
 * Function called when the display_message_panel timer tick.
 */
static void display_message_panel_timeout_handler(void* p_context) {
	UNUSED_PARAMETER(p_context);
	display_message_panel_change_page();
}

/**
 * Function called when the service_time_update timer tick.
 */
static void service_time_update_timeout_handler(void* p_context) {
	UNUSED_PARAMETER(p_context);
	service_time_update();
}

/**
 * Function called when the activity_header_refresh timer tick.
 */
static void activity_header_refresh_timeout_handler(void* p_context) {
	UNUSED_PARAMETER(p_context);
	activity_header_refresh();
}

/**
 * Function called when the service_geolocation_upload timer tick.
 */
static void service_geolocation_upload_timeout_handler(void* p_context) {
	UNUSED_PARAMETER(p_context);
	service_geolocation_send_current_geolocation();
}

/**
 * Function called when a button is pressed.
 */
static void app_button_handler(uint8_t pin_no, uint8_t button_action) {
	if (button_action == APP_BUTTON_PUSH)
	{
		if (LEFT_BUTTON_PIN_NUMBER == pin_no)
			display_menu_handle_left_button_pushed();
		else if (RIGHT_BUTTON_PIN_NUMBER == pin_no)
			display_menu_handle_right_button_pushed();
	}
}

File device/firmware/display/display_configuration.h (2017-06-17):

#ifndef _DISPLAY_CONFIGURATION_H_
#define _DISPLAY_CONFIGURATION_H_

#define FONT_WIDTH         5
#define FONT_HEIGHT        7
#define FONT_MARGIN_RIGHT  1
#define FONT_MARGIN_BOTTOM 1
#define SCREEN_WIDTH       96
#define SCREEN_HEIGHT      96

#define FONT_WIDTH_WITH_MARGIN  (FONT_WIDTH + FONT_MARGIN_RIGHT)
#define FONT_HEIGHT_WITH_MARGIN (FONT_HEIGHT + FONT_MARGIN_BOTTOM)

#define HEADER_PANEL_HEIGHT     (FONT_HEIGHT_WITH_MARGIN + 1)
#define MENU_PANEL_HEIGHT       (FONT_HEIGHT_WITH_MARGIN + 1)

#define MAX_CHARACTERS_PER_LINE (SCREEN_WIDTH / FONT_WIDTH_WITH_MARGIN)

#endif

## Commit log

2017-06-14 Add the device 3D model.
    [BackCoverDecoration.scad, Battery1200mAh.scad, BleNano.scad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]
2017-06-16 Document 3d modeling.
    [back_cover.stl, brand_name.stl, front_cover.stl]
2017-06-16 Add a photo of 3d printed cases.
2017-06-17 Add explanations for wiring.
2017-06-17 Continue the wiring explanations.
